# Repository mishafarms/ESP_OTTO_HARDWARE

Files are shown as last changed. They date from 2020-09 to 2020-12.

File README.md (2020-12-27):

# OttoDIYESPShield
ESP32 hardware designs for OttoDIY

NOTICE: Most of this has now been verified and works ...

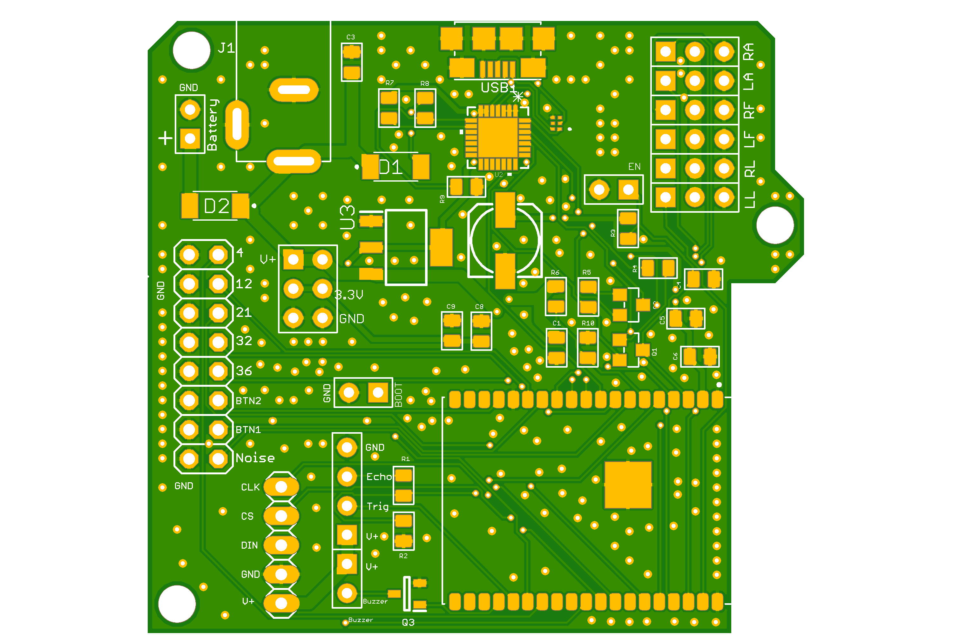
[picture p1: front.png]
Image of Yaktocat

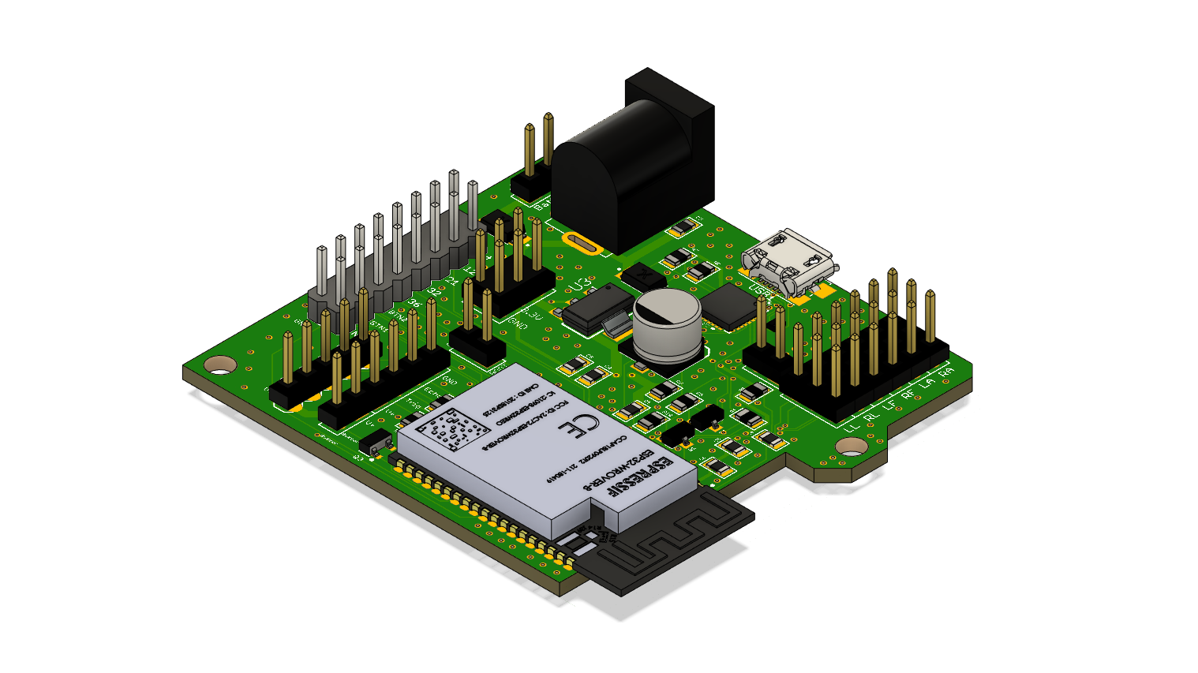
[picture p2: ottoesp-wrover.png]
Image of Nemo


I have created a fusion 360 Otto that has the proper holes in the head for this PCB, I am also including the STL files.
the legs have been modified to use the servos and horns I have.

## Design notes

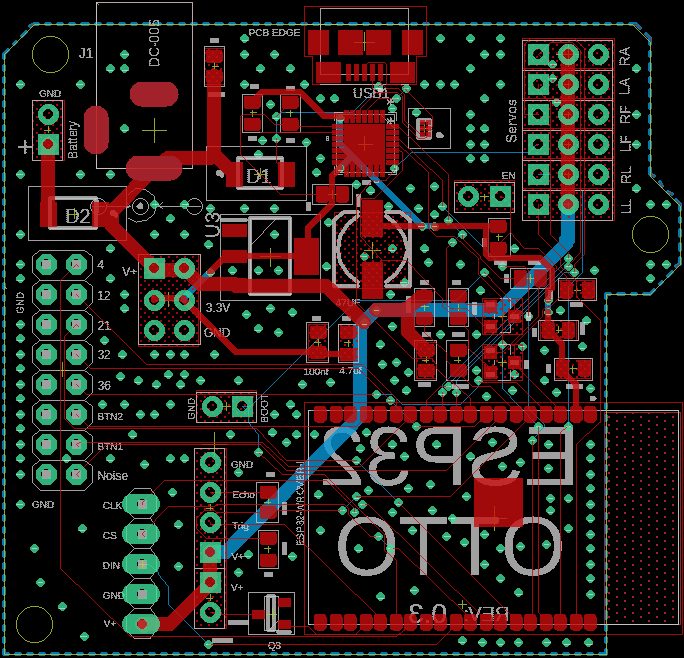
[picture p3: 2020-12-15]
layout.png

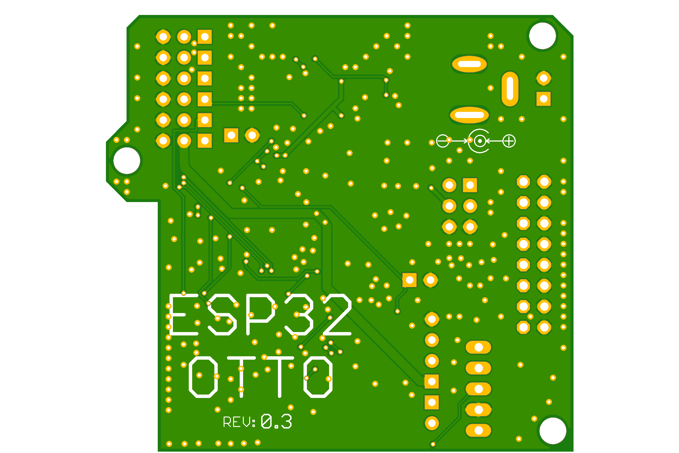
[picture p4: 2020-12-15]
back.png

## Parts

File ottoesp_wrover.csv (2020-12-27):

Part | Value | Device | Package | Description | CATEGORY | DESCRIPTION | DESIGNER | HEIGHT | MANUFACTURER | MANUFACTURER_NAME | MANUFACTURER_PART_NUMBER | MOUSER_PART_NUMBER | MOUSER_PRICE-STOCK | MPN | OPERATING_TEMP | PART_STATUS | REV | ROHS_COMPLIANT | SERIES | SUB-CATEGORY | THERMALLOSS | TYPE | VALUE
A1 | ESP32-WROVER-I | ESP32-WROVER-I | XCVR_ESP32-WROVER-I | ESP32 WROVER-IB |  | ESP-32 WROVER |  |  |  | Espressif Systems | ESP32-WROVER-IE(M213EH2864UH3Q0) | 356-ESP32WRVIE2864UC | https://www.mouser.com/ProductDetail/Espressif-Systems/ESP32-WROVER-IEM213EH2864UH3Q0/
C1 | 22uf | CERAMIC-22UF-6.3V-20%-X5R(0805) | C0805 | Capacitor 22uf 20% SMD 0805 |  | Capacitor 22uf 20% SMD 0805 |  |  |  | KEMET | C1206C226M9PACTU | 80-C1206C226M9P | https://www.mouser.com/ProductDetail/KEMET/C1206C226M9PACTU/?qs=e7A2guvi5TDfGn1mCprQAw%3D%3D |  |  |  |  |  |  |  |  |  | 22uf
C2 | 47UF | ALUMINUM-SMD-47UF-25V(D6.3-H5.3MM) | ELECTRO-SMD-C-6MM | Electrolytic Capacitors - SMD 25 Volts 47uF 20% 6.3x5.3 |  | Electrolytic Capacitors - SMD 25 Volts 47uF 20% 6.3x5.3 |  |  |  | Lelon | VE-470M1ETR-0605 | 140-VE470M1ETR0605 | https://www.mouser.com/ProductDetail/Lelon/VE-470M1ETR-0605/ |  |  |  |  |  |  |  |  |  | 47UF
C3 | 100nf | CERAMIC-100NF-50V-20%-X5R(0805) | C0805 | Capacitor 100nf 20% SMD 0805 |  | Capacitor 100nf 20% SMD 0805 |  |  |  | Yageo | CC0805ZRY5V9BB104 | 603-CC805ZRY5V9BB104 | https://www.mouser.com/ProductDetail/Yageo/CC0805ZRY5V9BB104/ |  |  |  |  |  |  |  |  |  | 100nf
C4 | 22uf | CERAMIC-22UF-6.3V-20%-X5R(0805) | C0805 | Capacitor 22uf 20% SMD 0805 |  | Capacitor 22uf 20% SMD 0805 |  |  |  | KEMET | C1206C226M9PACTU | 80-C1206C226M9P | https://www.mouser.com/ProductDetail/KEMET/C1206C226M9PACTU/?qs=e7A2guvi5TDfGn1mCprQAw%3D%3D |  |  |  |  |  |  |  |  |  | 22uf
C5 | 22uf | CERAMIC-22UF-6.3V-20%-X5R(0805) | C0805 | Capacitor 22uf 20% SMD 0805 |  | Capacitor 22uf 20% SMD 0805 |  |  |  | KEMET | C1206C226M9PACTU | 80-C1206C226M9P | https://www.mouser.com/ProductDetail/KEMET/C1206C226M9PACTU/?qs=e7A2guvi5TDfGn1mCprQAw%3D%3D |  |  |  |  |  |  |  |  |  | 22uf
C6 | 100nf | CERAMIC-100NF-50V-20%-X5R(0805) | C0805 | Capacitor 100nf 20% SMD 0805 |  | Capacitor 100nf 20% SMD 0805 |  |  |  | Yageo | CC0805ZRY5V9BB104 | 603-CC805ZRY5V9BB104 | https://www.mouser.com/ProductDetail/Yageo/CC0805ZRY5V9BB104/ |  |  |  |  |  |  |  |  |  | 100nf
C8 | 4.7uf | CERAMIC-4.7UF-25V-10%-X5R(0805) | C0805 | 302010146 |  | Capacitor 4.7uf 10% SMD 0805 |  |  |  | Walsin | 0805X475M250CT | 791-0805X475M250CT | https://www.mouser.com/ProductDetail/Walsin/0805X475M250CT/ |  |  |  |  |  |  |  |  |  | 4.7uf
C9 | 100nf | CERAMIC-100NF-50V-20%-X5R(0805) | C0805 | Capacitor 100nf 20% SMD 0805 |  | Capacitor 100nf 20% SMD 0805 |  |  |  | Yageo | CC0805ZRY5V9BB104 | 603-CC805ZRY5V9BB104 | https://www.mouser.com/ProductDetail/Yageo/CC0805ZRY5V9BB104/ |  |  |  |  |  |  |  |  |  | 100nf
D1 | PMEG3050EP,115 | PMEG3050EP,115 | PMEG3050EP115 | NXP PMEG3050EP,115 SMT Schottky Diode, 30V 5A, 2-Pin SOD-128 |  | NXP PMEG3050EP,115 SMT Schottky Diode, 30V 5A, 2-Pin SOD-128 |  | 1mm |  | Nexperia | PMEG3050EP,115 | 771-PMEG3050EP115 | https://www.mouser.co.uk/ProductDetail/Nexperia/PMEG3050EP115?qs=GcY6OjH1zdmnjQ%2FhUT5aOA%3D%3D
D2 | PMEG3050EP,115 | PMEG3050EP,115 | PMEG3050EP115 | NXP PMEG3050EP,115 SMT Schottky Diode, 30V 5A, 2-Pin SOD-128 |  | NXP PMEG3050EP,115 SMT Schottky Diode, 30V 5A, 2-Pin SOD-128 |  | 1mm |  | Nexperia | PMEG3050EP,115 | 771-PMEG3050EP115 | https://www.mouser.co.uk/ProductDetail/Nexperia/PMEG3050EP115?qs=GcY6OjH1zdmnjQ%2FhUT5aOA%3D%3D
FRAME1 | FRAME-LEDGERMISHAFARMS | FRAME-LEDGERMISHAFARMS | MISHAFARMS | Schematic Frame - Ledger |  |  | Michael Weiss |  |  |  |  |  |  |  |  |  | 0.3
J1 | DC-005 | CONN-POWER-JACK-2.1MM(DC-005) | DCJ3P-14.2X11.0X9.0MM | Seeed SKU 320120003 - DIP Black DC Jack 2.1MM |  |  |  |  |  |  |  |  |  | DC-005 |  |  |  |  |  |  |  |  | DC-005
J2 | 2x3p-2.54 | DIP-BLACK-MALE-HEADER(2X3P-2.54）-2.54 | H2X3-2.54 | 320020077 |  |  |  |  |  |  | P125-12A1BS116A1 |  |  |  |  |  |  |  |  |  |  |  | 2x3p-2.54
J3 | 4p-2.54 | DIP-BLACK-MALE-HEADER-VERT(4P-2.54) | H4-2.54 | 320020017 |  |  |  |  |  |  | P125-1104A0BS116A1 |  |  |  |  |  |  |  |  |  |  |  | 4p-2.54
JP1 | PINHD-2X8 | PINHD-2X8 | 2X08 | PIN HEADER | CONNECTOR |  |  |  |  |  |  |  |  |  |  |  |  |  |  | PIN-HEADER
JP2 | 2p-2.54 | DIP-BLACK-MALE-HEADER-VERT(2P-2.54) | H2-2.54 | 320020016 |  |  |  |  |  |  | P125-1102A0BS116A1 |  |  |  |  |  |  |  |  |  |  |  | 2p-2.54
JP3 | 2p-2.54 | DIP-BLACK-MALE-HEADER-VERT(2P-2.54) | H2-2.54 | 320020016 |  |  |  |  |  |  | P125-1102A0BS116A1 |  |  |  |  |  |  |  |  |  |  |  | 2p-2.54
JP4 | 2p-2.54 | DIP-BLACK-MALE-HEADER-VERT(2P-2.54) | H2-2.54 | 320020016 |  |  |  |  |  |  | P125-1102A0BS116A1 |  |  |  |  |  |  |  |  |  |  |  | 2p-2.54
JP5 | 2p-2.54 | DIP-BLACK-MALE-HEADER-VERT(2P-2.54) | H2-2.54 | 320020016 |  |  |  |  |  |  | P125-1102A0BS116A1 |  |  |  |  |  |  |  |  |  |  |  | 2p-2.54
JP6 |  | PINHD-1X5 | 1X05 | PIN HEADER
LA | 3p-2.54 | DIP-BLACK-MALE-HEADER-VERT(3P-2.54) | H3-2.54 | 320020079 |  |  |  |  |  |  |  |  |  |  |  |  |  |  |  |  |  |  | 3p-2.54
LF | 3p-2.54 | DIP-BLACK-MALE-HEADER-VERT(3P-2.54) | H3-2.54 | 320020079 |  |  |  |  |  |  |  |  |  |  |  |  |  |  |  |  |  |  | 3p-2.54
LL | 3p-2.54 | DIP-BLACK-MALE-HEADER-VERT(3P-2.54) | H3-2.54 | 320020079 |  |  |  |  |  |  |  |  |  |  |  |  |  |  |  |  |  |  | 3p-2.54
Q1 | S8050-G | SMD-TRANSISTORS-NPN-25V-500MW-S8050(SOT-23) | SOT-23 | NPN transistor |  |  |  |  |  |  | SS8050-G | 750-SS8050-G |  |  |  |  |  |  |  |  |  |  | S8050-G
Q2 | S8050-G | SMD-TRANSISTORS-NPN-25V-500MW-S8050(SOT-23) | SOT-23 | NPN transistor |  |  |  |  |  |  | SS8050-G | 750-SS8050-G |  |  |  |  |  |  |  |  |  |  | S8050-G
Q3 | CJ2302 | 2N7002NXAKR | SOT95P230X110-3N | NEXPERIA - 2N7002NXAKR - MOSFET Transistor, Trench, N Channel, 190 mA, 60 V, 3 ohm, 10 V, 1.6 V |  | NEXPERIA - 2N7002NXAKR - MOSFET Transistor, Trench, N Channel, 190 mA, 60 V, 3 ohm, 10 V, 1.6 V |  | 1.1mm |  | Nexperia | 2N7002NXAKR | 771-2N7002NXAKR | https://www.mouser.co.uk/ProductDetail/Nexperia/2N7002NXAKR/?qs=%252B6g0mu59x7JoAsZYPFXqhw%3D%3D
R1 | 10K | SMD-RES-10K-1%-1/4W(0805) | R0805 | Resistor 10K 1% |  | Resistor 10K 1% SMD 0805 |  |  |  | KOA Speer | RK73H2ATTD1002F | 660-RK73H2ATTD1002F | https://www.mouser.com/ProductDetail/KOA-Speer/RK73H2ATTD1002F/?qs=tLTLU8dkiwvc%2FyU3ERoqnw%3D%3D |  |  |  |  |  |  |  |  |  | 10K
R2 | 22K | SMD-RES-22K-5%-1/4W(0805) | R0805 | Resistor 22K 5% |  | Resistor 22K 5% SMD 0805 |  |  |  | KOA Speer | RK73B2ATTD223J | 660-RK73B2ATTD223J | https://www.mouser.com/ProductDetail/KOA-Speer/RK73B2ATTD223J/?qs=rx%252BqewZzWUffEp6AgUqu%252Bg%3D%3D |  |  |  |  |  |  |  |  |  | 22K
R3 | 10K | SMD-RES-10K-1%-1/4W(0805) | R0805 | Resistor 10K 1% |  | Resistor 10K 1% SMD 0805 |  |  |  | KOA Speer | RK73H2ATTD1002F | 660-RK73H2ATTD1002F | https://www.mouser.com/ProductDetail/KOA-Speer/RK73H2ATTD1002F/?qs=tLTLU8dkiwvc%2FyU3ERoqnw%3D%3D |  |  |  |  |  |  |  |  |  | 10K
R4 | 10K | SMD-RES-10K-1%-1/4W(0805) | R0805 | Resistor 10K 1% |  | Resistor 10K 1% SMD 0805 |  |  |  | KOA Speer | RK73H2ATTD1002F | 660-RK73H2ATTD1002F | https://www.mouser.com/ProductDetail/KOA-Speer/RK73H2ATTD1002F/?qs=tLTLU8dkiwvc%2FyU3ERoqnw%3D%3D |  |  |  |  |  |  |  |  |  | 10K
R5 | 10K | SMD-RES-10K-1%-1/4W(0805) | R0805 | Resistor 10K 1% |  | Resistor 10K 1% SMD 0805 |  |  |  | KOA Speer | RK73H2ATTD1002F | 660-RK73H2ATTD1002F | https://www.mouser.com/ProductDetail/KOA-Speer/RK73H2ATTD1002F/?qs=tLTLU8dkiwvc%2FyU3ERoqnw%3D%3D |  |  |  |  |  |  |  |  |  | 10K
R6 | 100K | SMD-RES-100K-.5%-1/10W(0805) | R0805 | Resistor 100K 0.5% |  | Resistor 100K 0.5% SMD 0805 |  |  |  | Susumu | RR1220P-104-D | 754-RR1220P-104D | https://www.mouser.com/ProductDetail/Susumu/RR1220P-104-D/ |  |  |  |  |  |  |  |  |  | 100K
R7 | 1K | SMD-RES-1K-1%-1/8W(0805) | R0805 | Resistor 1K 1% |  | Resistor 1K 1% SMD 0805 |  |  |  | Vishay / Dale | CRCW08051K00FKEAC | 71-CRCW08051K00FKEAC | https://www.mouser.com/ProductDetail/Vishay-Dale/CRCW08051K00FKEAC/ |  |  |  |  |  |  |  |  |  | 1K
R8 | 22K | SMD-RES-22K-5%-1/4W(0805) | R0805 | Resistor 22K 5% |  | Resistor 22K 5% SMD 0805 |  |  |  | KOA Speer | RK73B2ATTD223J | 660-RK73B2ATTD223J | https://www.mouser.com/ProductDetail/KOA-Speer/RK73B2ATTD223J/?qs=rx%252BqewZzWUffEp6AgUqu%252Bg%3D%3D |  |  |  |  |  |  |  |  |  | 22K
R9 | 47K | SMD-RES-47K-1%-1/4W(0805) | R0805 | Resistor 47K 1% |  | Resistor 47K 1% SMD 0805 |  |  |  | KOA Speer | RK73H2ATTD4702F | 660-RK73H2ATTD4702F | https://www.mouser.com/ProductDetail/KOA-Speer/RK73H2ATTD4702F/ |  |  |  |  |  |  |  |  |  | 47K
R10 | 100K | SMD-RES-100K-.5%-1/10W(0805) | R0805 | Resistor 100K 0.5% |  | Resistor 100K 0.5% SMD 0805 |  |  |  | Susumu | RR1220P-104-D | 754-RR1220P-104D | https://www.mouser.com/ProductDetail/Susumu/RR1220P-104-D/ |  |  |  |  |  |  |  |  |  | 100K
RA | 3p-2.54 | DIP-BLACK-MALE-HEADER-VERT(3P-2.54) | H3-2.54 | 320020079 |  |  |  |  |  |  |  |  |  |  |  |  |  |  |  |  |  |  | 3p-2.54
RF | 3p-2.54 | DIP-BLACK-MALE-HEADER-VERT(3P-2.54) | H3-2.54 | 320020079 |  |  |  |  |  |  |  |  |  |  |  |  |  |  |  |  |  |  | 3p-2.54
RL | 3p-2.54 | DIP-BLACK-MALE-HEADER-VERT(3P-2.54) | H3-2.54 | 320020079 |  |  |  |  |  |  |  |  |  |  |  |  |  |  |  |  |  |  | 3p-2.54
U$2 | ESP32_SHIELDSMALL | ESP32_SHIELDSMALL | ESP32_ARDUINOSHIELDSMALL | Board pattern for Otto
U2 | CP2102 | CP2102 | QFN28N5X5-0P5P | USB to UART |  | USB-UART |  |  |  | Silicon Labs | CP2102N-A02-GQFN28R | 634-CP2102NA02QFN28R | https://www.mouser.com/ProductDetail/Silicon-Labs/CP2102N-A02-GQFN28R/?qs=u16ybLDytRag4qKvSH3fTw%3D%3D
U3 | CJA1117B-3.3-SOT89 | AP2114H-3.3TRG1 | SOT230P700X180-4N | 1A 3.3V Low Noise LDO Regulator SOT223 DiodesZetex AP2114H-3.3TRG1, LDO Voltage Regulator, 1 (Min)A, 3.3 V +/-1.5%, 2.5 6 Vin, 3-Pin SOT-223 |  | 1A 3.3V Low Noise LDO Regulator SOT223 DiodesZetex AP2114H-3.3TRG1, LDO Voltage Regulator, 1 (Min)A, 3.3 V +/-1.5%, 2.5 6 Vin, 3-Pin SOT-223 |  | 1.8mm |  | Diodes Inc. | AP2114H-3.3TRG1 | 621-AP2114H-3.3TRG1 | https://www.mouser.co.uk/ProductDetail/Diodes-Incorporated/AP2114H-33TRG1?qs=x6A8l6qLYDDSG%2FfwzcsOhw%3D%3D
U4 | TPD4S012DRYR | TPD4S012DRYR | TPD4S012DRYR | ESD Suppressors / TVS Diodes 4Ch USB ESD Solution w/ Pwr Clamp |  | ESD Suppressors / TVS Diodes 4Ch USB ESD Solution w/ Pwr Clamp |  | 0.6mm |  | Texas Instruments | TPD4S012DRYR | 595-TPD4S012DRYR | https://www.mouser.co.uk/ProductDetail/Texas-Instruments/TPD4S012DRYR?qs=XGzIaZb%2FFYJve%2FbrCpoVgg%3D%3D
USB1 | ZX62-B-5PA | ZX62-B-5PA(33) | HRS_ZX62-B-5PA(33) | ZX Series 5 Position Right Angle PCB Wire Micro B USB Plug |  | USB Micro B female connector |  |  |  | Hirose Connector | ZX62-B-5PA(33) | 798-ZX62-B-5PA33 | https://www.mouser.com/ProductDetail/Hirose-Connector/ZX62-B-5PA33/

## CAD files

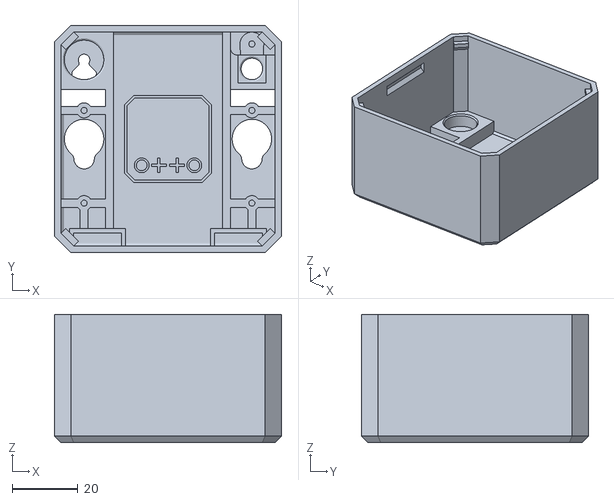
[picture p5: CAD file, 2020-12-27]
Body.stl
69.0 x 69.0 x 39.0

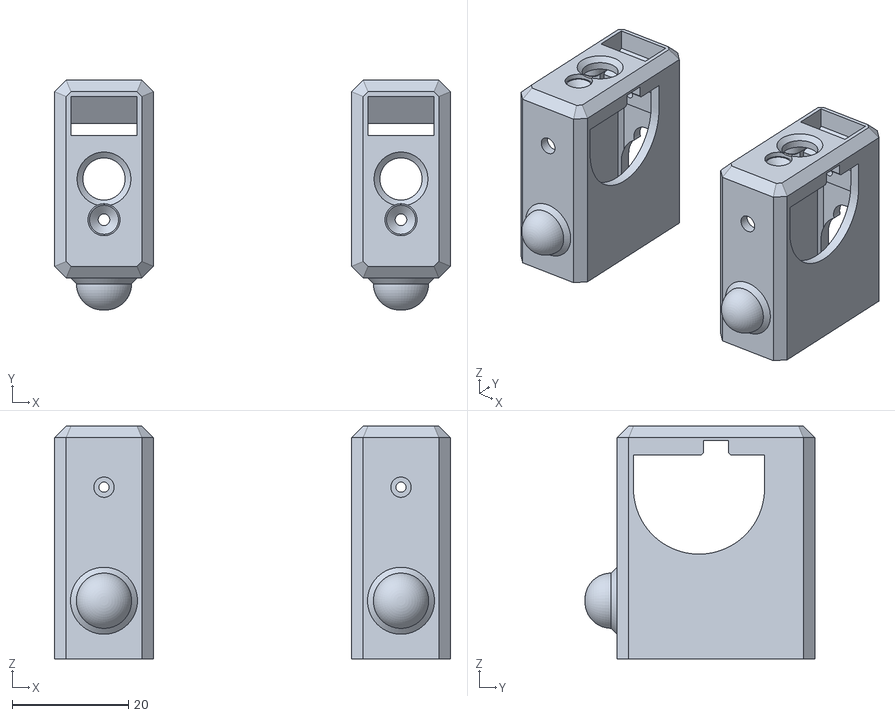
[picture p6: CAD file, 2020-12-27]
Leg.stl
68.0 x 39.5 x 40.0

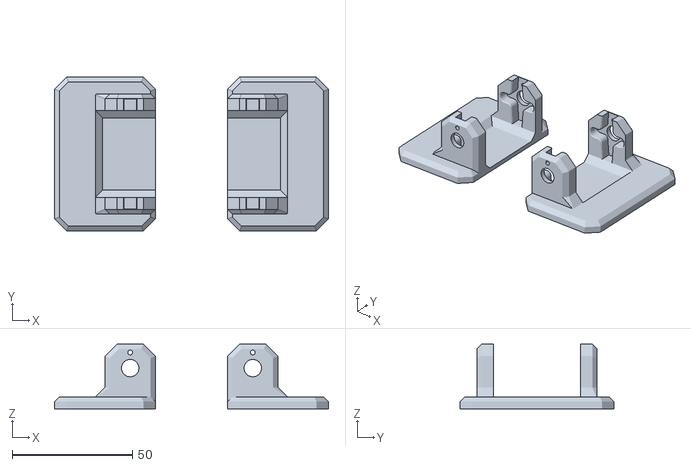
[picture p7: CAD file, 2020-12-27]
Feet.stl
114.0 x 64.0 x 27.0

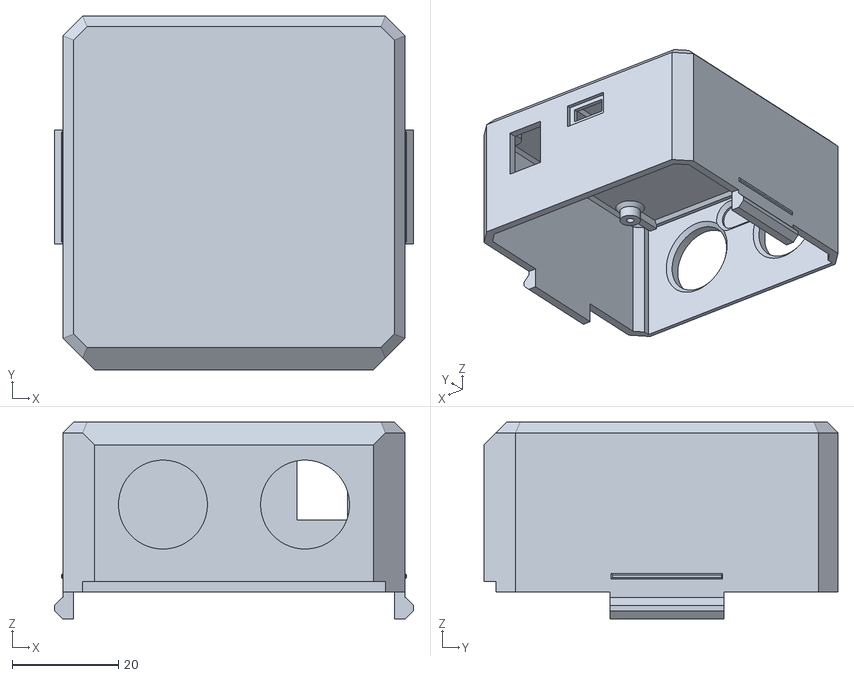
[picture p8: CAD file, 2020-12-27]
Head.stl
67.6 x 66.7 x 37.0

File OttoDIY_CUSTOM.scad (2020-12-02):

// Part to print
part="head"; // [all:Preview Bot,head:Head,body:Body,leg:Leg,foot_left:Left Foot,foot_right:Right Foot]

// Brain type (hole pattern in head)
brain_type="esp32_shield"; // [nano_shield:Stock (Arduino Nano + Servo Shield),nano_proto:Arduino Nano + Proto board,uno_shield:Arduino Uno + Servo Shield,uno:Arduino Uno (and wires)]

// Servo Type for hip
servo_type_hip="sg90"; // [sg90:SG90 (nylon gear micro servo),mg90s:MG90S (metal gear micro servo)]

// Servo Type for ankle
servo_type_ankle="sg90"; // [sg90:SG90 (nylon gear micro servo),mg90s:MG90S (metal gear micro servo)]

// Body Width (Head width is based off this)
body_width=71; // [67:200]

// Body Depth (Head depth is based off this)
body_depth=72; // [68:200]

// Body Height
body_height=38; // [20:200]

// Head Height
head_height=34; // [20:200]

// Body Shell Thickness
body_thickness=1.75; // [0.25:0.25:8]

// Head Shell Thickness
head_thickness=2; // [0.25:0.25:8]

// Nose Diameter (6 = Small Toggle Switch)
nose_diameter=6; // [0:24]
// Vertical distance between center of eyes and nose
nose_distance=15; // [-8:190] 

// Brain Screw Size (2 = Stock)
brain_screw_size=2; // [2:5]

// Make Brain Screw thru Skull
brain_screw_thru=0; // [1:Yes,0:No]

// Solid leg
leg_solid=0; // [1:Yes, solid,0:No, my printer doesn't like those overhangs]

/* [Hidden] */
part_clearance=0.25;

arduino_holes=[[-27,-7],[-27,20.9],[25.2,26.1],[23.825,-22.25]];
proto_holes=[[27,-10],[-17.9,-10],[26,25.5],[-17.7,25.5]];

esp32_holes=[[27,7],[-25.2,-26.1],[-23.825,22.25]];

print_part();

module print_part() {
  warnings()
    draw_part();
}

module draw_part() {
  if(part=="head")
    head();
  else if(part=="body")
    body();
  else if(part=="leg")
    leg();
  else if(part=="foot_left")
    foot();
  else if(part=="foot_right")
    mirror([1,0]) foot();
  else if(part=="all")
    rotate([0,0,-90]) otto();
}
module otto() {
  head(move=1);
  body(move=1);
  mirrory() {
    translate([0,body_width/2-33.5,0])
    {
      mirror([1,0]) foot(move=1);
      translate([0,24,-1]) mirror([0,0,1]) leg(move=0);
    }
  }
}
function brain_type_text() = (
  brain_type=="nano_shield"?"Arduino Nano + Servo Shield":(
  brain_type=="uno_shield"?"Arduino Uno + Servo Shield":(
  brain_type=="nano_proto"?"Arduino Nano + Proto board":(
  brain_type=="esp32_shield"?"ESP32 Shield":"Unknown"))));
module warnings() {
  if(brain_type=="nano_shield")
  {
    if(body_width<67)
      error(str("If ",brain_type_text()," is used, Body Width must be >= 67!"));
    else if(body_depth<67)
      error(str("If ",brain_type_text()," is used, Body Depth must be >= 67!"));
    else children();
  } else if(brain_type=="esp32_shield")
  {
    if( body_width<71)
      error(str("If ",brain_type_text()," is used, Body Width must be >= 71!"));
    else if(body_depth<72)
      error(str("If ",brain_type_text()," is used, Body Depth must be >= 72!"));
    else children();
  } else if(brain_type=="uno_shield"||brain_type=="uno")
  {
    if(body_width<81)
      error("If Arduino Uno is used, body width MUST be greater than 81!");
    else children();
  } else children();
}
module error(s) {
  echo(str("***ERROR*** ",s));
  rotate([0,0,-45])
        rotate([80,0,0]) color("red") text(s);
}
module body(dims=[body_depth-1,body_width,body_height]) {
  left=dims[0]/-2; // -33.5
  botm=dims[1]/-2; // -33.5
  right=dims[0]/2; // 34
  servozoff=servo_type_hip=="sg90"?2:0;
  *#import("Otto_DIY/files/OTTO_body_v3.stl");
  mirrorx(0.4) mirrory(0.25) translate([left+body_thickness,botm+body_thickness+13.775,body_thickness]) {
      cube([dims[0]/2-9,2.5,12.4]);
      translate([0,2.5,12.39]) rotate([90,0,90]) mirror([1,0]) linear_extrude(dims[0]/2-9,convexity=10) polygon([[0,0],[1.2,0.825],[2.5,0.825],[2.5,0]]);
  }
  mirrory() mirrorx() translate([left+body_thickness-.01,botm+6,dims[2]-16]) difference(){
    cube([2,13.7,5]);
    translate([0,-.01]) rotate([0,41]) cube([3,13.72,5]);
  }
  mirrory() for(x=[0,28.2]) translate([x-9.5,botm+body_thickness,body_thickness]) difference() {
    union(){
      cube([2,13.775,6.18-servozoff]);
      translate([0.98,6.85,0]) cylinder(d1=5.7,d2=4.4,h=0.85,$fn=30);
      translate([0.98,6.85,0.84]) cylinder(d=4.4,h=5.35-servozoff,$fn=40);
    }
      translate([0.98,6.85,-.01]) cylinder(d=1.9,h=7,$fn=20);
  }
  for(mx=[0,1],my=[0,1]) mirror([mx,0]) mirror([0,my]) translate([mx?-11:0,0])
  translate([left+body_thickness+22.2,botm+body_thickness,body_thickness]) difference() { union() {
      if(!mx&&!my)
        translate([-10.7,6.61])
          cylinder(d=16,h=6.25-servozoff,$fn=50);
      else if(!mx&&my)
        translate([-17.5,0,.01]) cube([11.9,13.2,6-servozoff]);
      translate([-1-(left+33),5.64,0]) mirror([1,0]) cube([(mx?-22:-12)-left,2,6.1-servozoff]);
    }
    if(!mx&&!my)
      translate([-10.72,6.61,-.01]) cylinder(d=12,h=6.27,$fn=40);
    else if(!mx&&my)
      translate([-15.9,5,-.01]) {
        cube([8.35,8.2,7]);
        translate([0,-6]) cube([8.35,4,7]);
      }
  }
  difference() {
      translate([left,botm,0]) box_chamfer(dims,ch=2,chvx=5,chvy=5);
//    translate([left+1.75,botm+1.75,2]) box_chamfer([dims[0]-3.5,dims[1]-3.5,dims[2]],ch=1,chvx=4,chvy=4,inside=1);
    translate([left+body_thickness,botm+body_thickness,2]) box_chamfer([dims[0]-body_thickness*2,dims[1]-body_thickness*2,dims[2]],ch=1,chvx=4,chvy=4,inside=1);
    translate([0,0,-1]) linear_extrude(10,convexity=10) {
      mirrory() {
        translate([.1,botm+8.5]) circle(d=12,$fn=30);
        translate([6,botm+8.5]) circle(d=servo_type_hip=="mg90s"?6.5:7,$fn=20);
        offset(-1) offset(1)
        translate([-14.5,-15]) square([29,4]);
      }
      translate([left+9,-botm-13.5]) square([5.2,5.2]);
      translate([left+12.8,botm+8.35]) {
        circle(d=2,$fn=20);
        for(r=[2:360/7:359]) rotate([0,0,r]) translate([4.1,0]) circle(d=2,$fn=20);
      }
    }
    mirrory() translate([-11.7,right-body_thickness-.51,dims[2]-11]) {  cube([22.35,body_thickness+0.6,4]);
      translate([0,body_thickness+.02,4.1]) rotate([-35,0]) mirror([0,0,1]) mirror([0,1,0]) cube([22.35,4,5.4]);
    }
  }
}
module head(dims=[
    body_width-(body_thickness+part_clearance)*2,
    body_depth-(body_thickness+part_clearance)*2,
    head_height],brain_type=brain_type,head_thickness=head_thickness,move=0) {
  left=dims[0]/-2; // -31.5
  botm=dims[1]/-2; // -32.25
  right=dims[0]/2; // 31.5
  translate(move?[0,0,body_height+head_height-3]:[0,0,0]) rotate(move?[180,0,-90]:[0,0,0]) {
    //#import("Otto_DIY/files/OTTO_head_v3.stl");
    difference(){
      translate([left,botm,0]) box_chamfer(dims,ch=2,chy1=3.5,chvx=5.5,chvy=4);
      translate([left+head_thickness,botm+head_thickness+1.501,head_thickness]) box_chamfer([dims[0]-head_thickness*2,dims[1]-head_thickness*2-1.5,dims[2]],ch=1,chvx=2.75,chvy=2.75,inside=1);
      translate([left,botm-.01,dims[2]-3.8]) cube([dims[0],1.5,10]);
      for(x=[-13.25,13.25])
        translate([x,botm-.01,15]) rotate([-90,0]) cylinder(d=16.5,h=4,$fn=50);
      brain_holes(brain_type,top=dims[1]/2-20,right=dims[0]/2);
      translate([-5.6,-29.555,3.75]) {
        translate([11.25,0]) rotate([-90,0]) rotate([0,0,180]) intersection() {
          box_chamfer([11.3,7.6,2],ch=0,chvx=1.6,chvy=1.6);
          translate([0,0,-.8]) box_chamfer([11.3,7.6,4],ch=1.6,chvx=0,chvy=0);
          
        }
      }
      if(nose_diameter>0&&dims[2]-(nose_diameter/2+nose_distance)>18)
      {
        translate([0,botm-.01,15+nose_distance]) rotate([-90,0]) cylinder(d=nose_diameter,h=head_thickness+2.02,$fn=30);
      } else echo(str("Warning: Hiding nose."));
    }
    // tabs
    mirrorx() translate([-left-2,-9.25,dims[2]]) rotate([-90,0]) mirror([0,1,0]) linear_extrude(21,convexity=10) polygon([[0,0],[0,8.4],[1.98,8.4],[4.1,6.3],[4.1,4.2],[2,2.5],[2,0],]);
    mirrory(0.75) mirrorx(0) translate([left+4.5,botm+1.5,dims[2]]) rotate([90,0]) mirror([0,0,1]) linear_extrude(2) polygon([[0,0],[0,6],[2,8],[12,8],[14,6],[14,1.5],[15.5,0]]);
    brain(brain_type=brain_type,top=dims[1]/2-20,right=dims[0]/2);
  }
}
module leg(move=0) {
  bo=servo_type_ankle=="sg90"?0:(
    servo_type_ankle=="mg90s"?1.6:0);
  translate(move?[0,24,-40]:[]) rotate([0,0,0]) union(){
  //#import("Otto_DIY/files/OTTO_leg_v4.stl");
  difference() {
    translate([-14.5,-8.25,0]) {
      intersection() {
        cube([29,16.5,38.5]);
        union(){
          box_chamfer([29,16.5,20],2);
          translate([0,0,38.6]) mirror([0,0,1]) box_chamfer([29,16.5,20],1.25,chvx=2,chvy=2);
          *translate([1,1,30])
            box_chamfer2([29-2,16.5-2,7],2);
        }
      }
    }
    translate([-12.5,-6.25,4.25]) cube([25,12.5,50]);
    translate([12,-3,5]) cube([6,6,7.5]);
    translate([0.5,0,2.6-(servo_type_hip=="mg90s"?0:1)]) rotate([0,0,90]) {
      linear_extrude(3.4) 
        polygon([[-3.1,0],[-2,20],[2,20],[2.8,0]]); 
      translate([0,0,-3.01]) cylinder(d=servo_type_ankle=="mg90s"?7.8:7.4,h=8,$fn=30);
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

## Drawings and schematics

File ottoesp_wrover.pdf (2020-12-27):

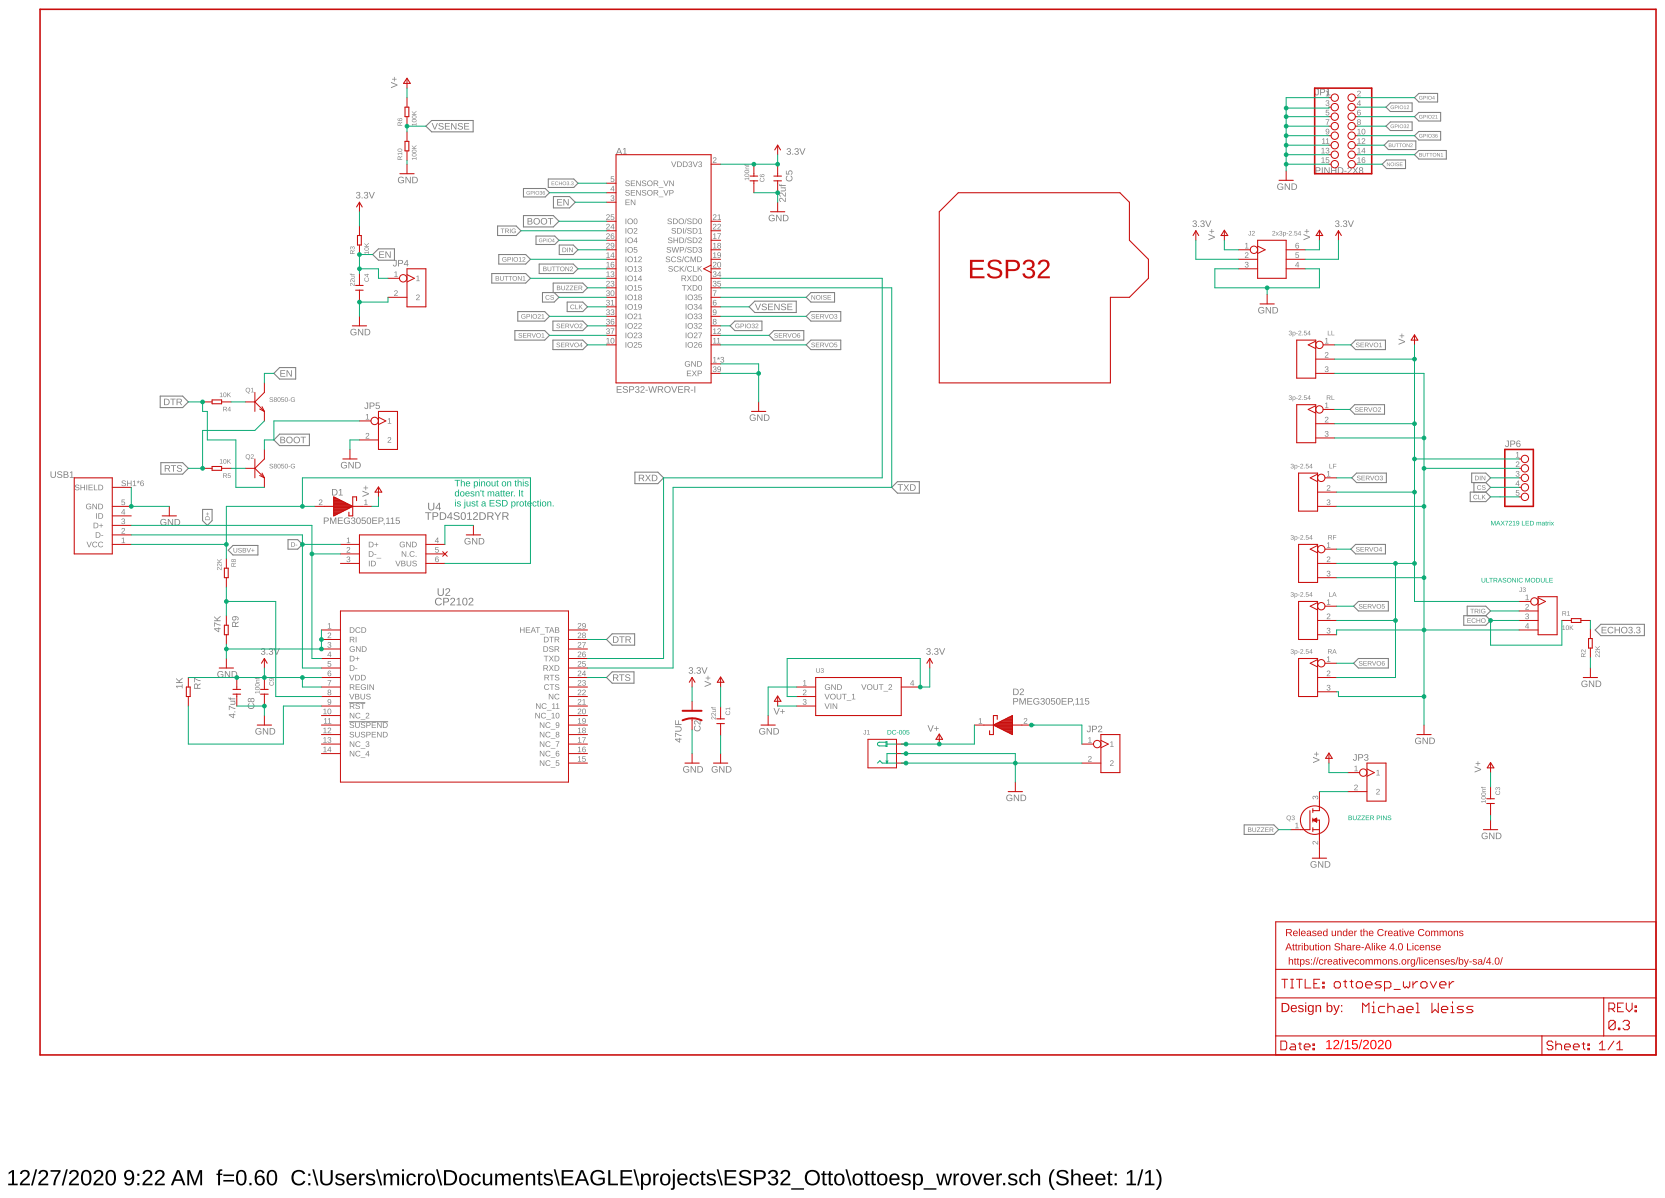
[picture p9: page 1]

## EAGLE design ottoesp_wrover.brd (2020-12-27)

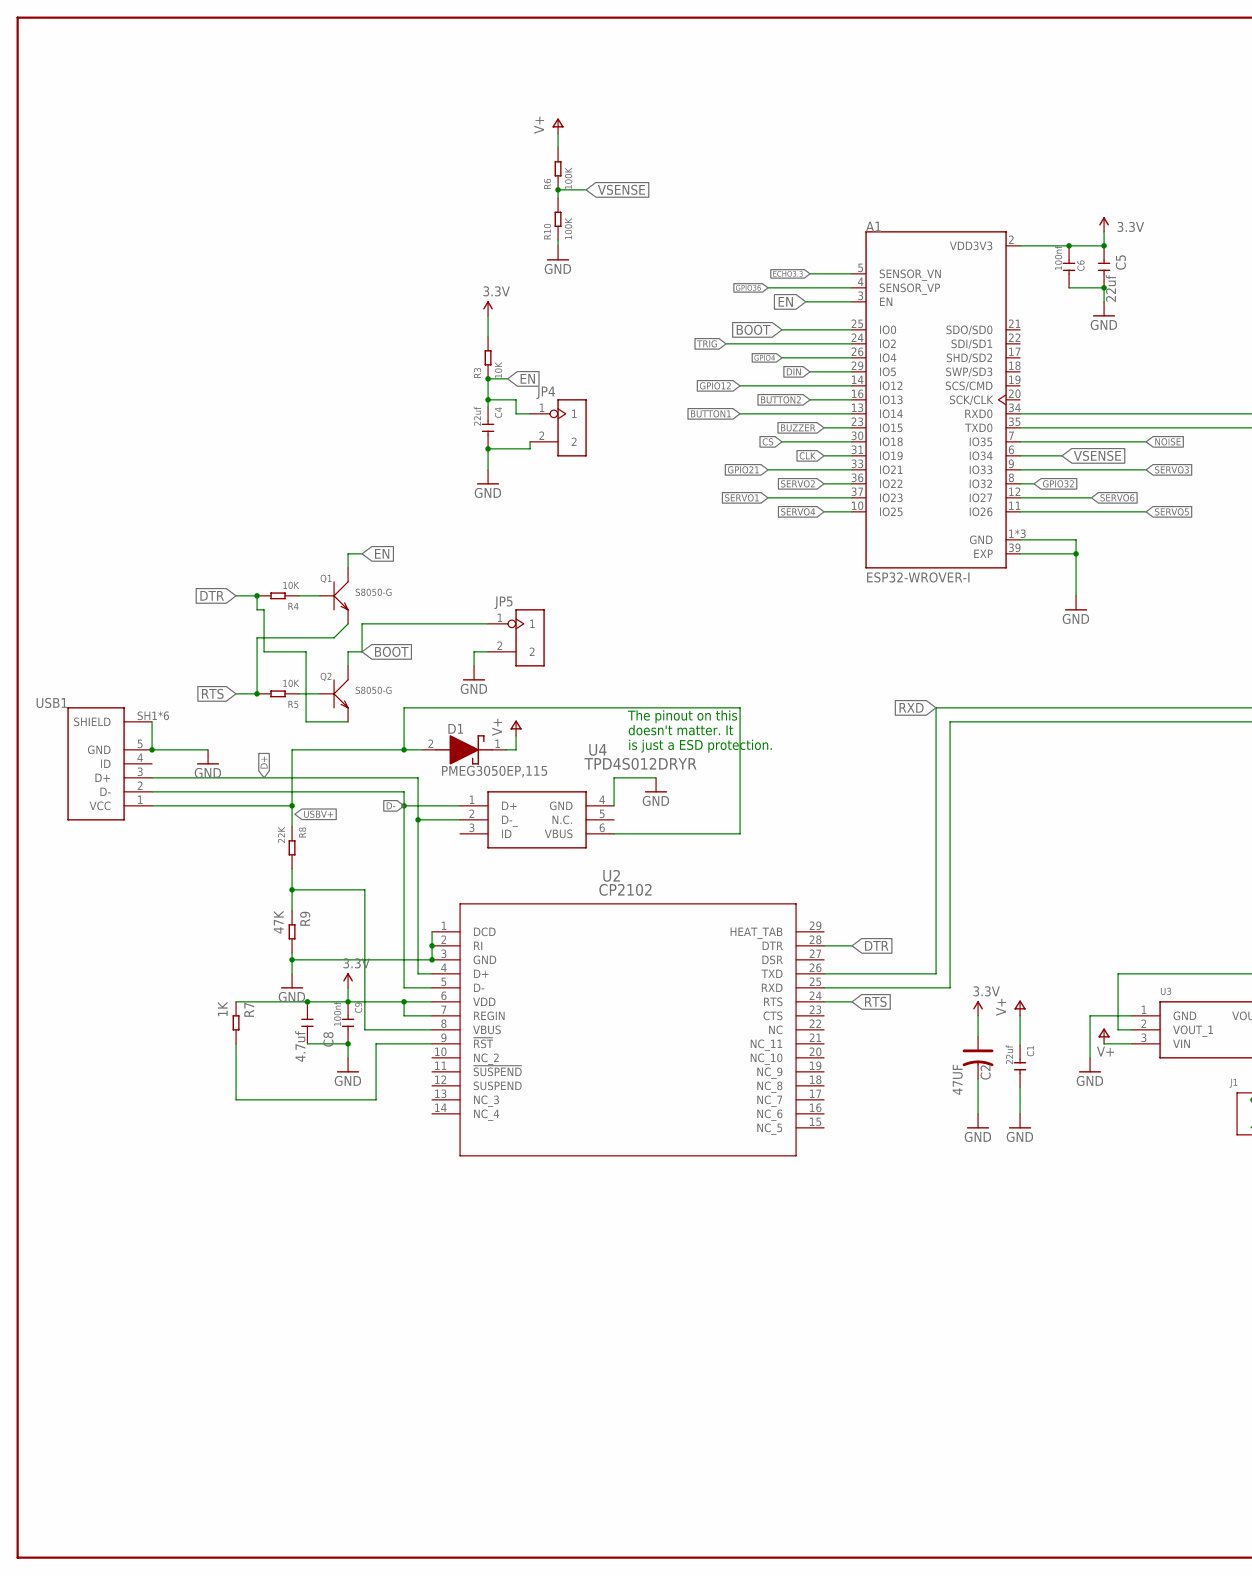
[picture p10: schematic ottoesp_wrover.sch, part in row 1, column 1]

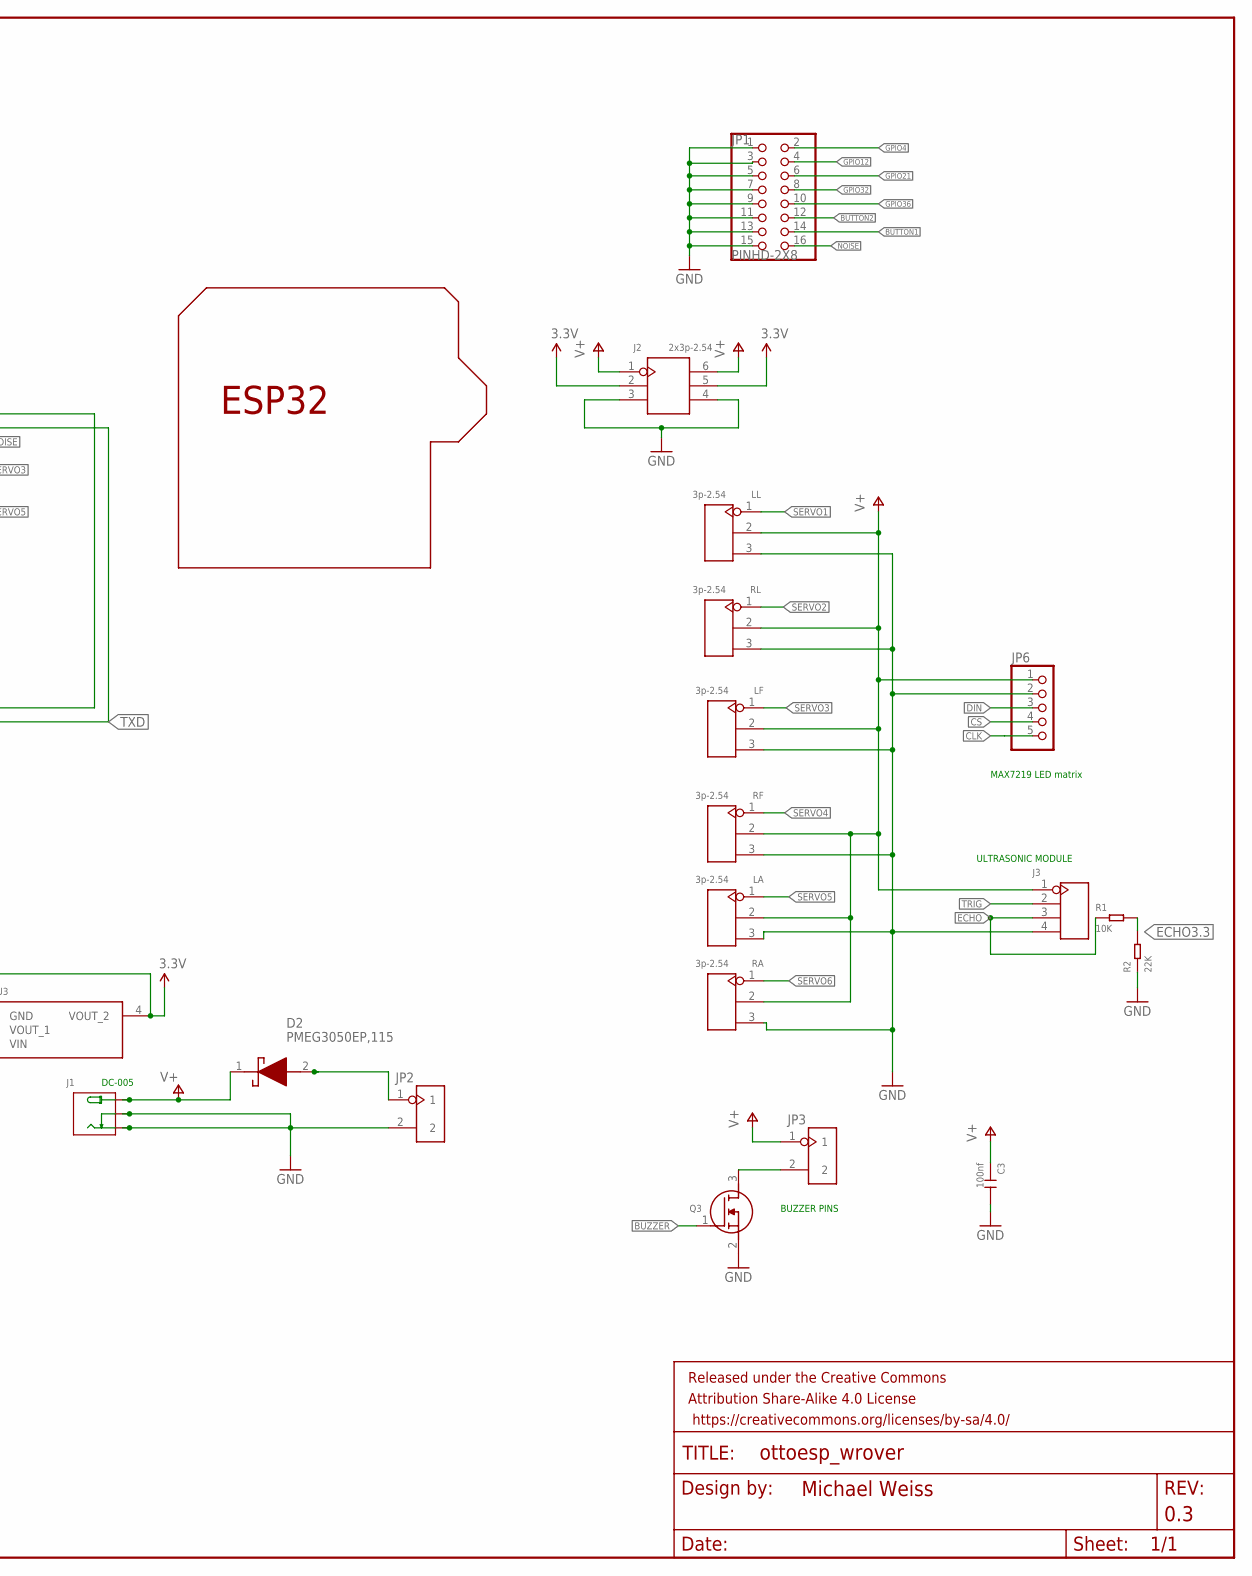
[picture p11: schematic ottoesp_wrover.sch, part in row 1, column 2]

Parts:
A1: ESP32-WROVER-I; XCVR_ESP32-WROVER-I
C1, C4, C5: 22uf; C0805
C2: 47UF; ELECTRO-SMD-C-6MM
C3, C6, C9: 100nf; C0805
C8: 4.7uf; C0805
D1, D2: PMEG3050EP,115; PMEG3050EP115
FRAME1: FRAME-LEDGERMISHAFARMS; MISHAFARMS
J1: DC-005; DCJ3P-14.2X11.0X9.0MM
J2: 2x3p-2.54; H2X3-2.54
J3: 4p-2.54; H4-2.54
JP1: PINHD-2X8; 2X08
JP2, JP3, JP4, JP5: 2p-2.54; H2-2.54
JP6: PINHD-1X5; 1X05
LA: 3p-2.54; H3-2.54
LF: 3p-2.54; H3-2.54
LL: 3p-2.54; H3-2.54
Q1, Q2: S8050-G; SOT-23
Q3: CJ2302; SOT95P230X110-3N
R1, R3, R4, R5: 10K; R0805
R2, R8: 22K; R0805
R6, R10: 100K; R0805
R7: 1K; R0805
R9: 47K; R0805
RA: 3p-2.54; H3-2.54
RF: 3p-2.54; H3-2.54
RL: 3p-2.54; H3-2.54
U2: CP2102; QFN28N5X5-0P5P
U3: CJA1117B-3.3-SOT89; SOT230P700X180-4N
U4: TPD4S012DRYR
U$2: ESP32_SHIELDSMALL; ESP32_ARDUINOSHIELDSMALL
USB1: ZX62-B-5PA; HRS_ZX62-B-5PA(33)

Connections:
3.3V: A1.2 (VDD3V3), C2.+, C5.1, C6.1, C8.1, C9.1, J2.2, J2.5, R3.2, R7.1, U2.6 (VDD), U2.7 (REGIN), U3.2 (VOUT_1), U3.4 (VOUT_2)
BOOT: A1.25 (IO0), JP5.1, Q2.3 (C)
BUTTON1: A1.13 (IO14), JP1.14
BUTTON2: A1.16 (IO13), JP1.12
BUZZER: A1.23 (IO15), Q3.1 (G)
CLK: A1.31 (IO19), JP6.5
CS: A1.30 (IO18), JP6.4
D+: U2.4 (D+), U4.2 (D-_), USB1.3 (D+)
D-: U2.5 (D-), U4.1 (D+), USB1.2 (D-)
DIN: A1.29 (IO5), JP6.3
DTR: Q2.2 (E), R4.2, U2.28 (DTR)
ECHO: J3.3, R1.1
ECHO3.3: A1.5 (SENSOR_VN), R1.2, R2.2
EN: A1.3 (EN), C4.1, JP4.1, Q1.3 (C), R3.1
GND: A1.1 (GND), A1.15 (GND), A1.38 (GND), A1.39 (EXP), C1.2, C2.-, C3.2, C4.2, C5.2, C6.2, C8.2, C9.2, J1.-1B (-), J1.-1T (-), J1.-2 (CDN), J1.-2B (CDN), J2.3, J2.4, J3.4, JP1.1, JP1.3, JP1.5, JP1.7, JP1.9, JP1.11, JP1.13, JP1.15, JP2.2, JP4.2, JP5.2, JP6.2, LA.3, LF.3, LL.3, Q3.2 (S), R2.1, R9.2, R10.1, RA.3, RF.3, RL.3, U2.1 (DCD), U2.2 (RI), U2.3 (GND), U3.1 (GND), U4.4 (GND), USB1.5 (GND), USB1.SH1 (SHIELD), USB1.SH2 (SHIELD), USB1.SH3 (SHIELD), USB1.SH4 (SHIELD), USB1.SH5 (SHIELD), USB1.SH6 (SHIELD)
GPIO4: A1.26 (IO4), JP1.2
GPIO12: A1.14 (IO12), JP1.4
GPIO21: A1.33 (IO21), JP1.6
GPIO32: A1.8 (IO32), JP1.8
GPIO36: A1.4 (SENSOR_VP), JP1.10
unnamed: JP3.2, Q3.3 (D)
unnamed: Q1.1 (B), R4.1
unnamed: Q2.1 (B), R5.1
unnamed: R7.2, U2.9 (!RST)
unnamed: R8.2, R9.1, U2.8 (VBUS)
unnamed: D2.2 (A), JP2.1
NOISE: A1.7 (IO35), JP1.16
RTS: Q1.2 (E), R5.2, U2.24 (RTS)
RXD: A1.34 (RXD0), U2.26 (TXD)
SERVO1: A1.37 (IO23), LL.1
SERVO2: A1.36 (IO22), RL.1
SERVO3: A1.9 (IO33), LF.1
SERVO4: A1.10 (IO25), RF.1
SERVO5: A1.11 (IO26), LA.1
SERVO6: A1.12 (IO27), RA.1
TRIG: A1.24 (IO2), J3.2
TXD: A1.35 (TXD0), U2.25 (RXD)
USBV+: D1.2 (A), R8.1, U4.6 (VBUS), USB1.1 (VCC)
V+: C1.1, C3.1, D1.1 (K), D2.1 (K), J1.+B (+), J1.+T (+), J2.1, J2.6, J3.1, JP3.1, JP6.1, LA.2, LF.2, LL.2, R6.2, RA.2, RF.2, RL.2, U3.3 (VIN)
VSENSE: A1.6 (IO34), R6.1, R10.2

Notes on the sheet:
MAX7219 LED matrix
ULTRASONIC MODULE
BUZZER PINS
The pinout on this doesn't matter. It is just a ESD protection.

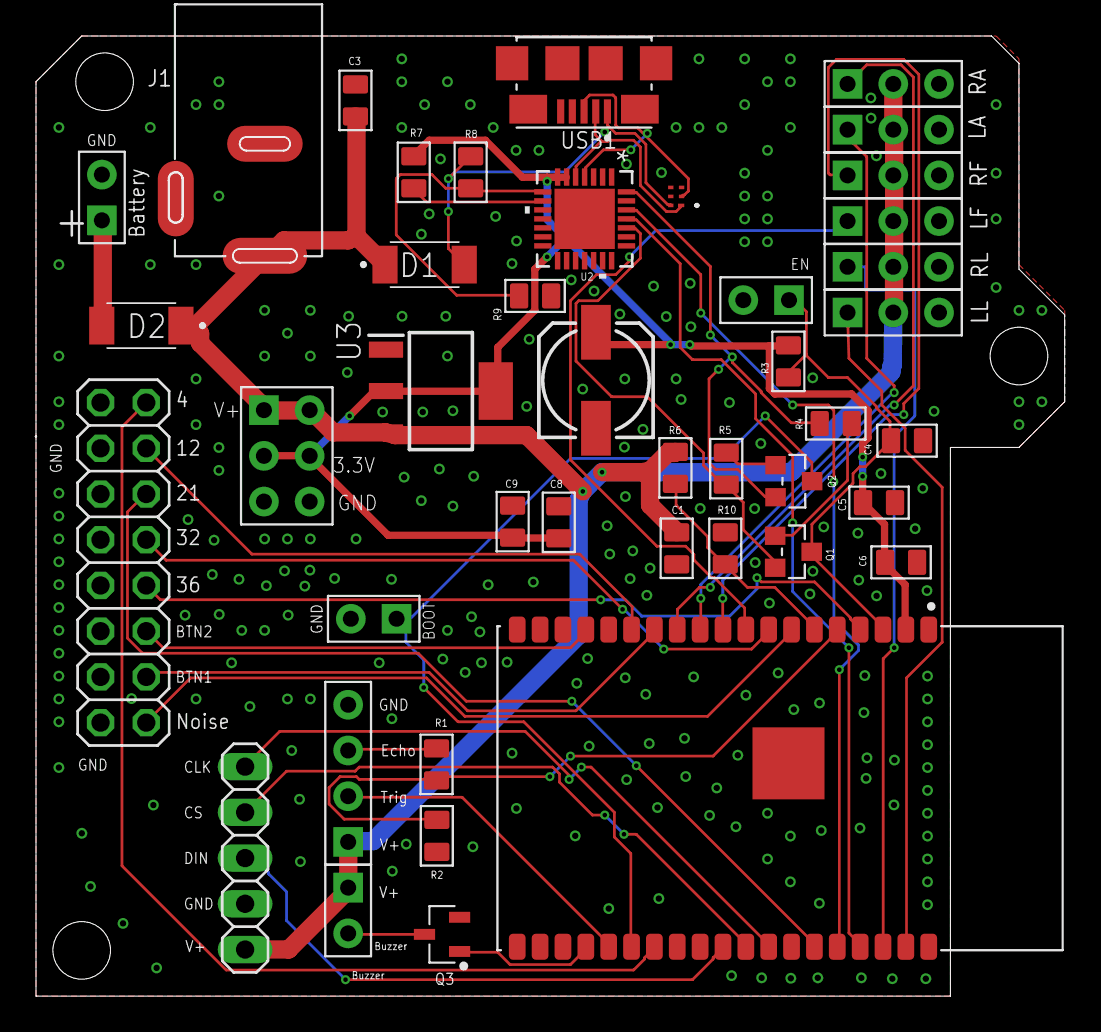
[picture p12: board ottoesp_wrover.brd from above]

Board: 2 copper layers, 57.2 x 53.3 mm, 45 parts (0 on the bottom side), 40 nets.

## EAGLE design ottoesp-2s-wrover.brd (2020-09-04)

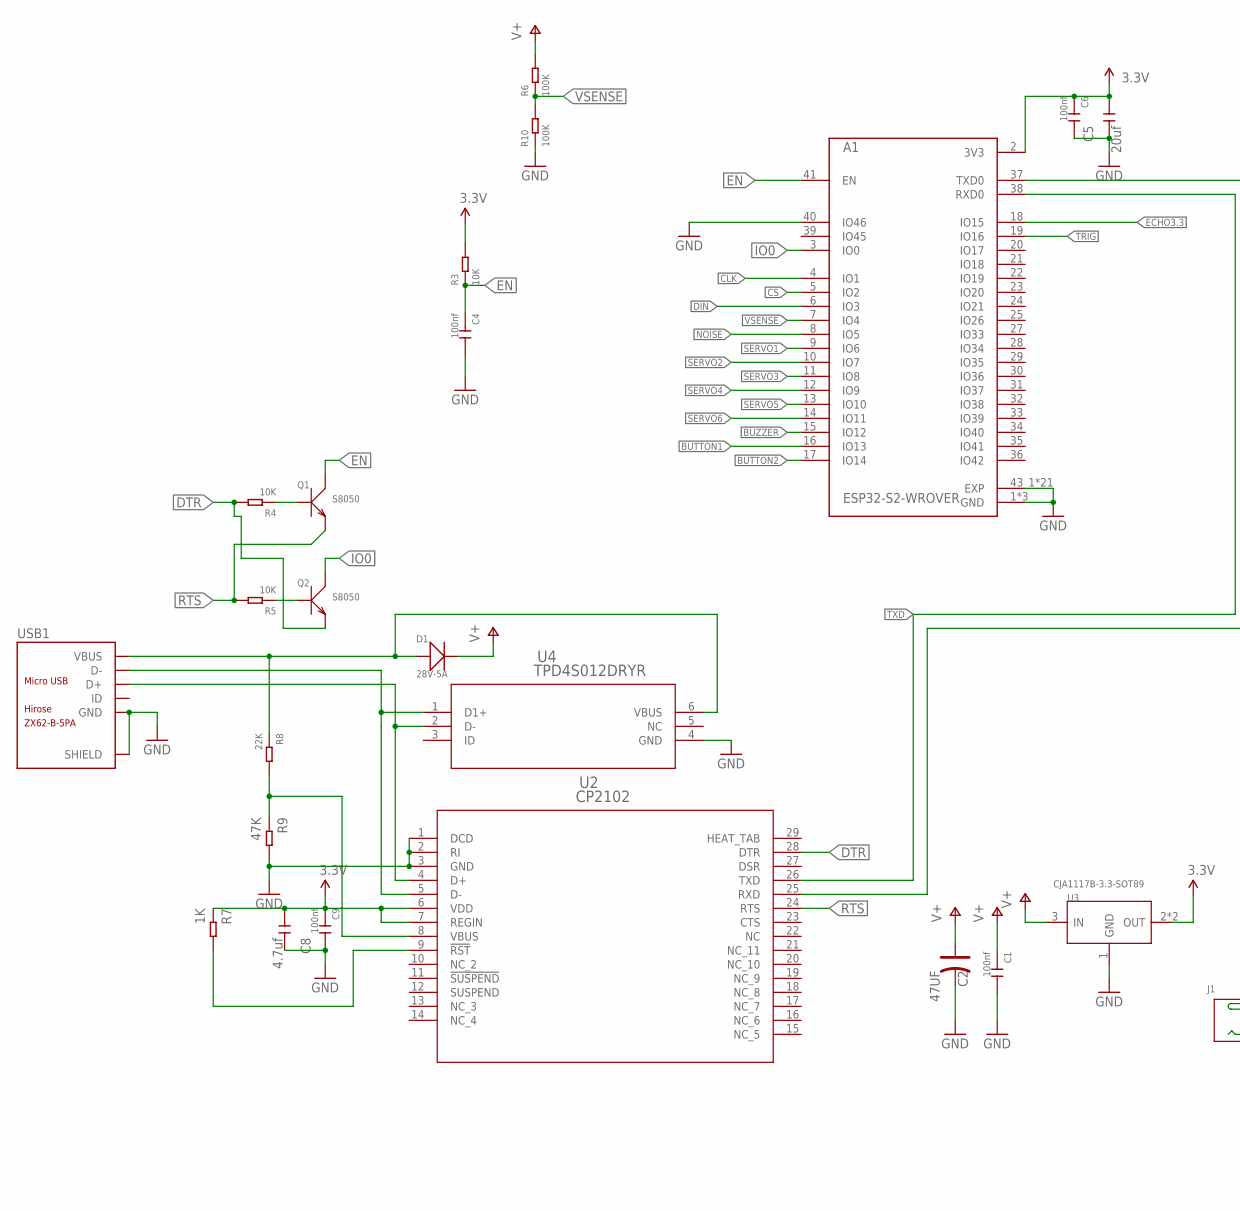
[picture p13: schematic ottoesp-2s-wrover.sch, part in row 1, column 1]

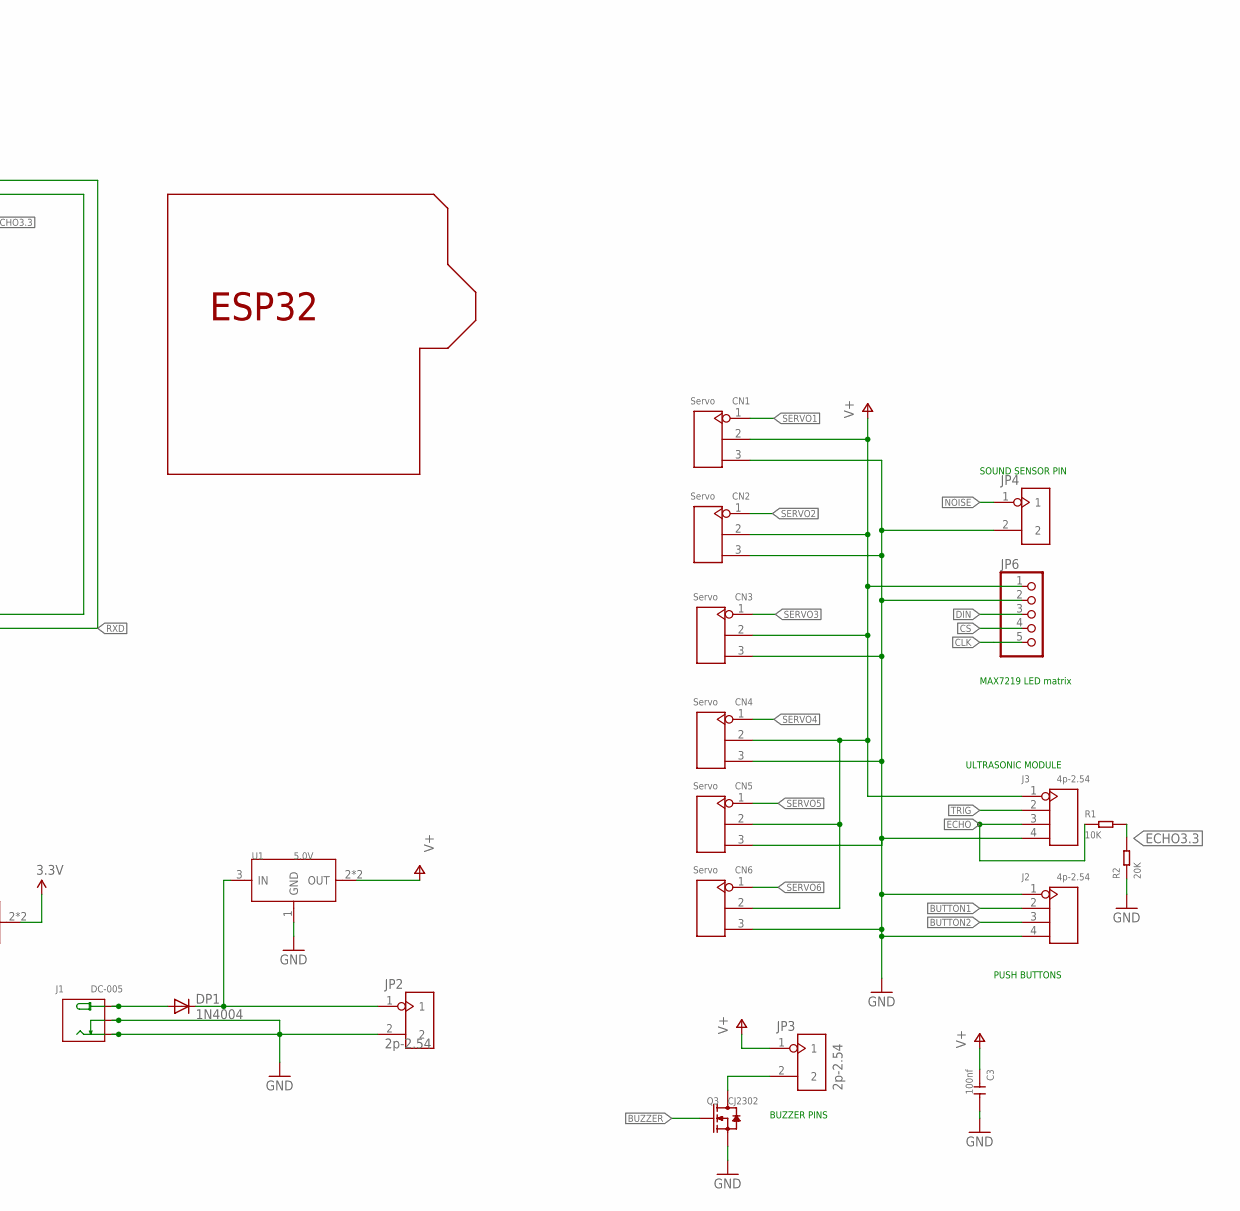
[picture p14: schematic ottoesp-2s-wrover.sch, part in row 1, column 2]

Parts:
A1: ESP32-S2-WROVER; MODULE_ESP32-S2-WROVER
C1, C3, C4, C6, C9: 100nf; C0805
C2: 47UF; ELECTRO-SMD-C-6MM
C5: 20uf; C1206
C8: 4.7uf; C0805
CN1, CN2, CN3, CN4, CN5, CN6: Servo; H3-2.54
D1: 28V-5A; DO-214AA
DP1: 1N4004; DO41-10
J1: DC-005; DCJ3P-14.2X11.0X9.0MM
J2, J3: 4p-2.54; H4-2.54
JP2, JP3, JP4: 2p-2.54; H2-2.54
JP6: PINHD-1X5; 1X05
Q1, Q2: S8050; SOT-23
Q3: CJ2302; SOT-23
R1, R3, R4, R5: 10K; R0805
R2: 20K; R0805
R6, R10: 100K; R0805
R7: 1K; R0805
R8: 22K; R0805
R9: 47K; R0603
U1: 5.0V; SOT-223
U2: CP2102; QFN28N5X5-0P5P
U3: CJA1117B-3.3-SOT89; SOT-89
U4: TPD4S012DRYR; DRY6
U$2: ESP32_SHIELDSMALL; ESP32_ARDUINOSHIELDSMALL
USB1: ZX62-B-5PA; MICRO-USB5+6P-SMD-0.65-AB

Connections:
3.3V: A1.2 (3V3), C5.1, C6.1, C8.1, C9.1, R3.2, R7.1, U2.6 (VDD), U2.7 (REGIN), U3.2 (OUT), U3.4 (OUT)
BUTTON1: A1.16 (IO13), J2.2
BUTTON2: A1.17 (IO14), J2.3
BUZZER: A1.15 (IO12), Q3.1 (G)
CLK: A1.4 (IO1), JP6.5
CS: A1.5 (IO2), JP6.4
DIN: A1.6 (IO3), JP6.3
DTR: Q2.2 (E), R4.2, U2.28 (DTR)
ECHO: J3.3, R1.1
ECHO3.3: A1.18 (IO15), R1.2, R2.2
EN: A1.41 (EN), C4.1, Q1.3 (C), R3.1
GND: A1.1 (GND), A1.26 (GND), A1.40 (IO46), A1.42 (GND), A1.43_1 (EXP), A1.43_2 (EXP), A1.43_3 (EXP), A1.43_4 (EXP), A1.43_5 (EXP), A1.43_6 (EXP), A1.43_7 (EXP), A1.43_8 (EXP), A1.43_9 (EXP), A1.43_10 (EXP), A1.43_11 (EXP), A1.43_12 (EXP), A1.43_13 (EXP), A1.43_14 (EXP), A1.43_15 (EXP), A1.43_16 (EXP), A1.43_17 (EXP), A1.43_18 (EXP), A1.43_19 (EXP), A1.43_20 (EXP), A1.43_21 (EXP), C1.2, C2.-, C3.2, C4.2, C5.2, C6.2, C8.2, C9.2, CN1.3, CN2.3, CN3.3, CN4.3, CN5.3, CN6.3, J1.-1 (-), J1.-2 (CDN), J2.1, J2.4, J3.4, JP2.2, JP4.2, JP6.2, Q3.2 (S), R2.1, R9.2, R10.1, U1.1 (GND), U2.1 (DCD), U2.2 (RI), U2.3 (GND), U3.1 (GND), U4.4 (GND), USB1.5 (GND), USB1.P1 (SHIELD), USB1.P2 (SHIELD), USB1.P3 (SHIELD), USB1.P4 (SHIELD), USB1.P5 (SHIELD), USB1.P6 (SHIELD)
IO0: A1.3 (IO0), Q2.3 (C)
unnamed: JP3.2, Q3.3 (D)
unnamed: Q1.1 (B), R4.1
unnamed: Q2.1 (B), R5.1
unnamed: R7.2, U2.9 (!RST)
unnamed: R8.2, R9.1, U2.8 (VBUS)
unnamed: U2.5 (D-), U4.1 (D1+), USB1.2 (D-)
unnamed: DP1.A, J1.+
unnamed: U2.4 (D+), U4.2 (D-), USB1.3 (D+)
unnamed: DP1.C, JP2.1, U1.3 (IN)
NOISE: A1.8 (IO5), JP4.1
RTS: Q1.2 (E), R5.2, U2.24 (RTS)
RXD: A1.37 (TXD0), U2.25 (RXD)
SERVO1: A1.9 (IO6), CN1.1
SERVO2: A1.10 (IO7), CN2.1
SERVO3: A1.11 (IO8), CN3.1
SERVO4: A1.12 (IO9), CN4.1
SERVO5: A1.13 (IO10), CN5.1
SERVO6: A1.14 (IO11), CN6.1
TRIG: A1.19 (IO16), J3.2
TXD: A1.38 (RXD0), U2.26 (TXD)
V+: C1.1, C2.+, C3.1, CN1.2, CN2.2, CN3.2, CN4.2, CN5.2, CN6.2, D1.-, J3.1, JP3.1, JP6.1, R6.2, U1.2 (OUT), U1.TER (OUT), U3.3 (IN)
VBUS: D1.+, R8.1, U4.6 (VBUS), USB1.1 (VBUS)
VSENSE: A1.7 (IO4), R6.1, R10.2

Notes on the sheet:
MAX7219 LED matrix
ULTRASONIC MODULE
PUSH BUTTONS
SOUND SENSOR PIN
BUZZER PINS

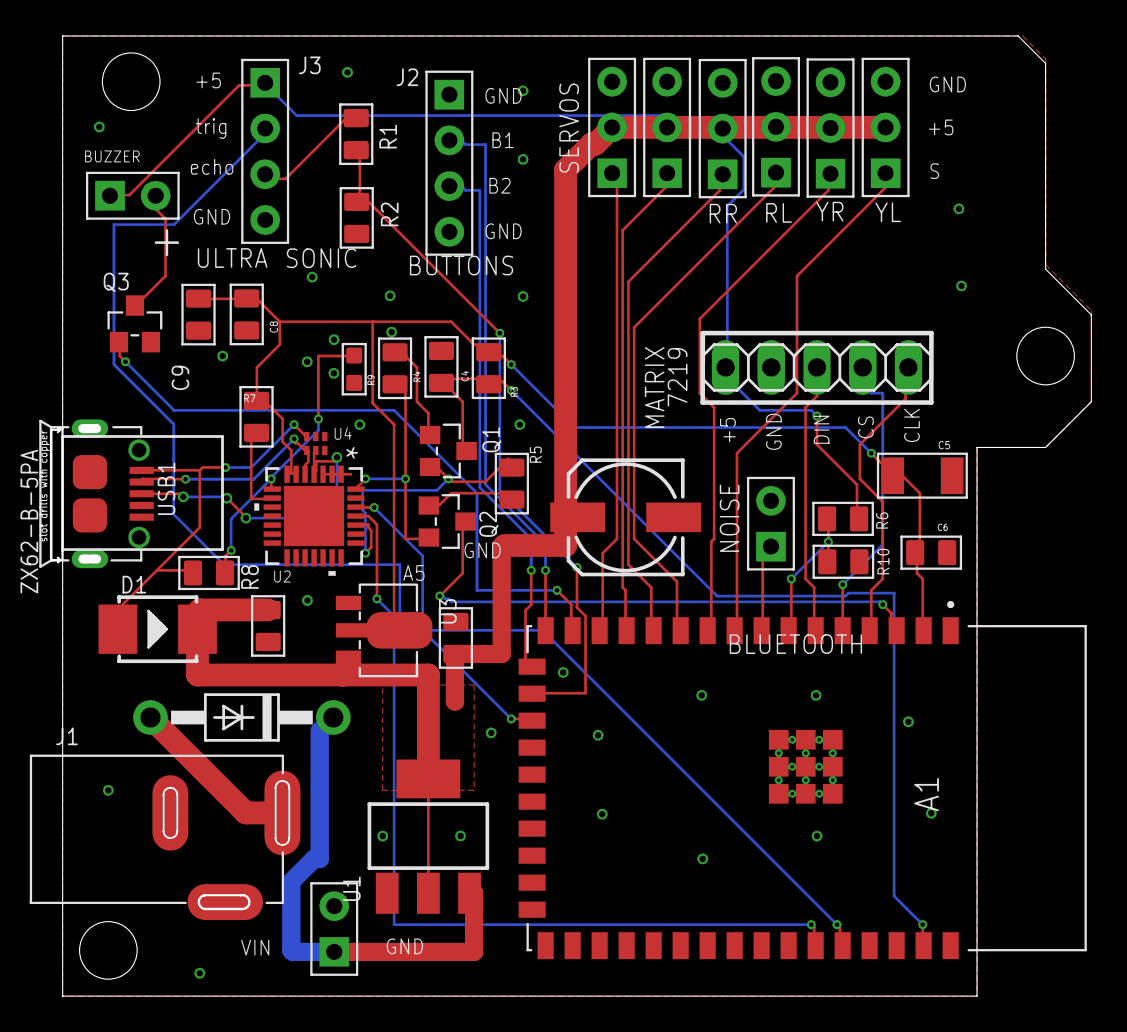
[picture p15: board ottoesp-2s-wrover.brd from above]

Board: 2 copper layers, 57.8 x 53.3 mm, 43 parts (0 on the bottom side), 36 nets.

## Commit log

2020-09-02 Initial Design
    [ottoesp-wrover.brd, ottoesp-wrover.sch]
2020-09-02 The pin names for the Matrix were incorrect
    [ottoesp-wrover.brd]
2020-09-04 Adding ESP32-S2 design
    [ottoesp-2s-wrover.brd, ottoesp-2s-wrover.sch]
2020-09-06 Moved pins to allow a better PCB routing. Fixed all DRC errors.
    [ottoesp-wrover.brd, ottoesp-wrover.sch]
2020-09-08 Updated to use parts I can find at mouser. Used a higher power 3.3V regulator. Added Gerber zip that I used to order prototype boards from SEEED.
    [ottoesp-wrover.brd, ottoesp-wrover.sch]
2020-09-09 .gitignore all the files that eagle creates that we don't want uploaded. Added the BOM in CSV (this is the BOM from Mouser) Changed a 20K resistor to 22K so that we don't need some many different res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
    [ottoesp-wrover.brd, ottoesp-wrover.csv, ottoesp-wrover.sch]
2020-10-12 The latest schematic and board layout
    [ottoesp-wrover.brd, ottoesp-wrover.sch]
2020-10-13 Added pins with V+, 3.3V, and GND for expansion
    [ottoesp-wrover.brd, ottoesp-wrover.sch]
2020-10-15 Changed some pin usage to give us as many extra I/O pins as possible. Added an EN and a BOOT jumper, so we can boot and load in emergency. Moved headers and changed some cap values.
    [ottoesp_wrover.brd, ottoesp_wrover.sch]
2020-10-15 changed the name of the gerber file
2020-10-15 changed the name of the schematic and board
    [ottoesp-wrover.brd, ottoesp-wrover.sch, ottoesp_wrover.csv]
2020-12-01 Updated cap. These have been produced and seem to work. Still testing
    [ottoesp_wrover.brd, ottoesp_wrover.sch]
2020-12-01 Added esp32_shield as new brain_type. A little tight. But a good start
    [OttoDIY_CUSTOM.scad]
2020-12-02 Moved the power and usb holes a little and increased the size a little.
    [OttoDIY_CUSTOM.scad]
2020-12-15 Changed to bew PCB with cutout on corner changed cap to 22uf
    [ottoesp_wrover.brd, ottoesp_wrover.sch]
2020-12-15 Moved the servo pins and some others closer together to allow the use of pin strips.
    [ottoesp_wrover.brd, ottoesp_wrover.sch]
2020-12-27 Latest board with 3d packages
    [ottoesp_wrover.brd, ottoesp_wrover.sch]
2020-12-27 Latest part list with mouser part #s
    [ottoesp_wrover.csv]
2020-12-27 STL files
    [Body.stl, Feet.stl, Head.stl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]

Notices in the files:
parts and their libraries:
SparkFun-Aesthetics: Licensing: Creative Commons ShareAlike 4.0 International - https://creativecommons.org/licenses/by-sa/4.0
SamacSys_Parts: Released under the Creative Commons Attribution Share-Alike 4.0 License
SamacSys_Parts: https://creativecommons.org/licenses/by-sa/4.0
